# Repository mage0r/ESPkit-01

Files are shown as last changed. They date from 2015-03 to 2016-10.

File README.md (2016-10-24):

ESPkit-01 - The breakout board for learning ESP-01's
=============

This project is designed as an easy to use adapter to connect your ESP-01 device to a standard serial connection.

Version 1.3 has expanded and now includes a full usb-to-serial chip right on the board.  If you'd prefer the simpiler version, follow this link to [Version 1.2](https://github.com/mage0r/ESPkit-01/tree/v1.2).

It has a program/general use button and a ws2812b to play with some blinky leds.  To enable the ws2812b, simply bridge the "pixel on" pads.

Don't forget to jump on to Andy's github and do the workshop! https://github.com/geekscape/nodemcu_esp8266

[Schematic available here](espkit-01.pdf?raw=true "Schematic")

[Gerber](http://gerblook.org/pcb/zZLnKLdKDrQhMTAEMa8F2Y)

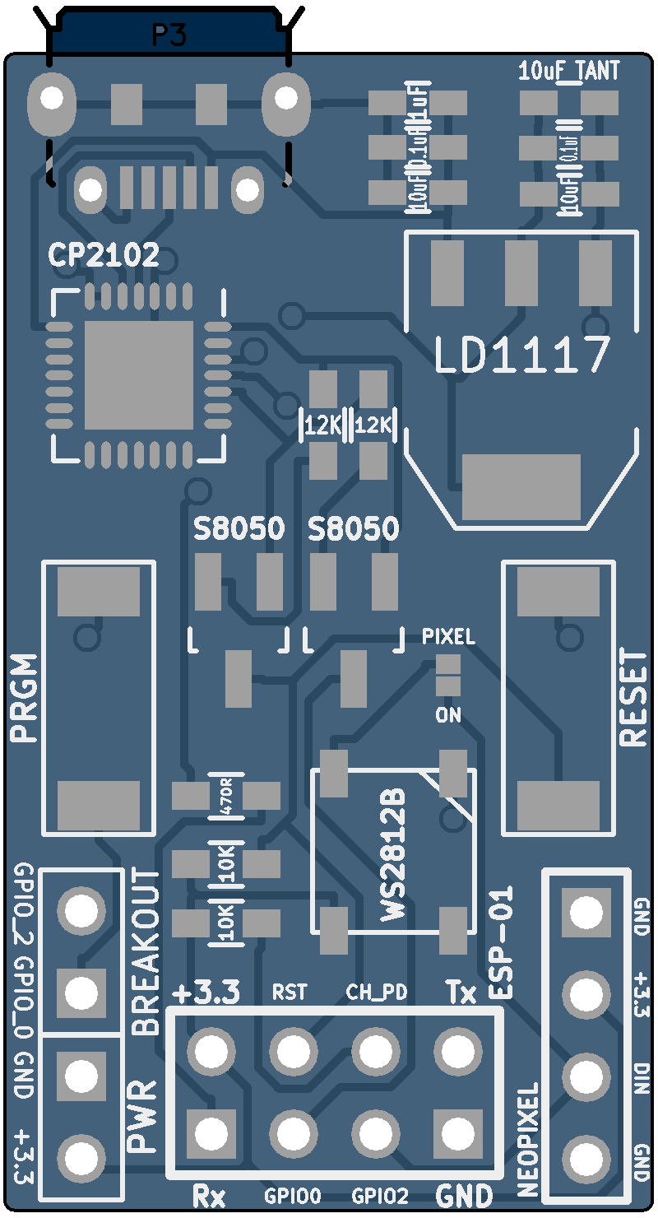
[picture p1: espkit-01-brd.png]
Board Layout board


CREDITS
------------

This project was designed by John Spencer and Andy Gelme
You can see our githubs at:
 - https://github.com/mage0r
 - https://github.com/geekscape

Made at hackmelbourne.org!

SPECIAL THANKS
------------

To the HackMelbourne (CCHS, http://hackmelbourne.org) community of Melbourne, Australia.

To all other open-source developers whose countless hours supported every other aspect of this design.

DISTRIBUTION
------------
The specific terms of distribution of this project are governed by the
license referenced below. Please contact the copyright owner if you wish to modify the board for distribution. Please utilize this design for personal or research projects. Please acknowledge all contributors.

LICENSE
-------
Licensed under the TAPR Open Hardware License (www.tapr.org/OHL).
The "license" sub-folder also contains a copy of this license in plain text format.

Copyright John Spencer, Andy Gelme 2016

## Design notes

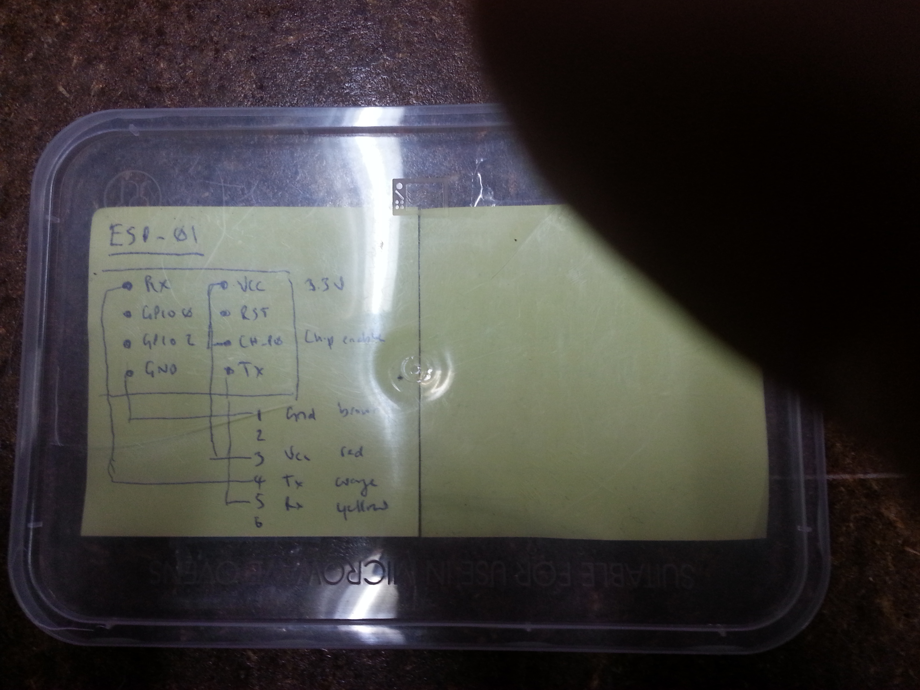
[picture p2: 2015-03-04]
Photos/Early Prototype.jpg

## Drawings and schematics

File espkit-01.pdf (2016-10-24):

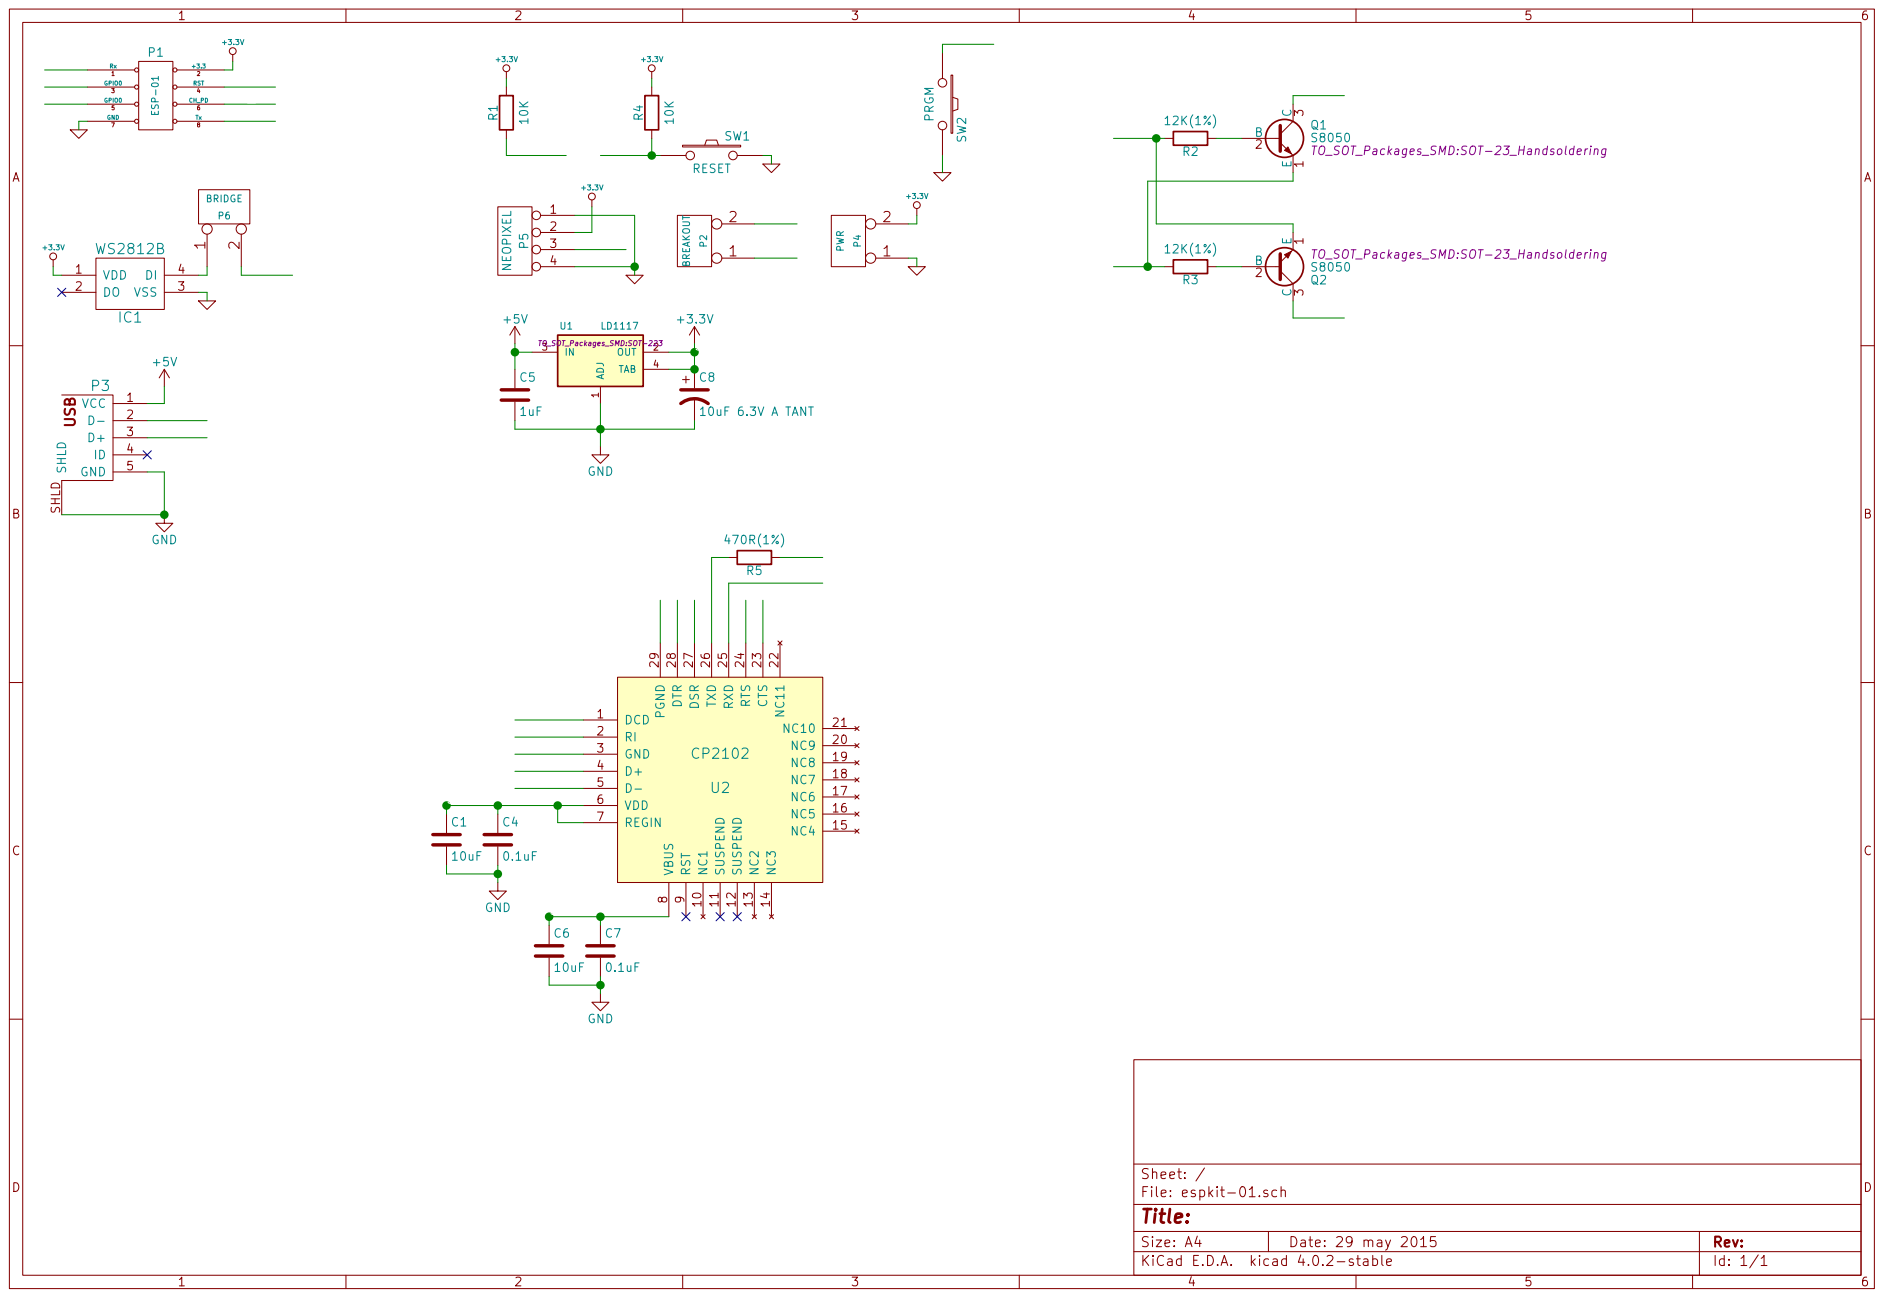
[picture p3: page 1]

File: espkit-01.sch Sheet: / SW2PRGM

9 NC1 10 NC9 20 SUSPEND 11 NC10 21 SUSPEND 12 NC11 22 NC2 13 CTS 23 NC3 14 RTS 24 NC4 15 RXD 25 NC5 16 TXD 26 NC6 17 DSR 27 NC7 18 DTR 28 NC8 19 PGND 29 U2 CP2102 USBVCC 1 D- 2 D+ 3

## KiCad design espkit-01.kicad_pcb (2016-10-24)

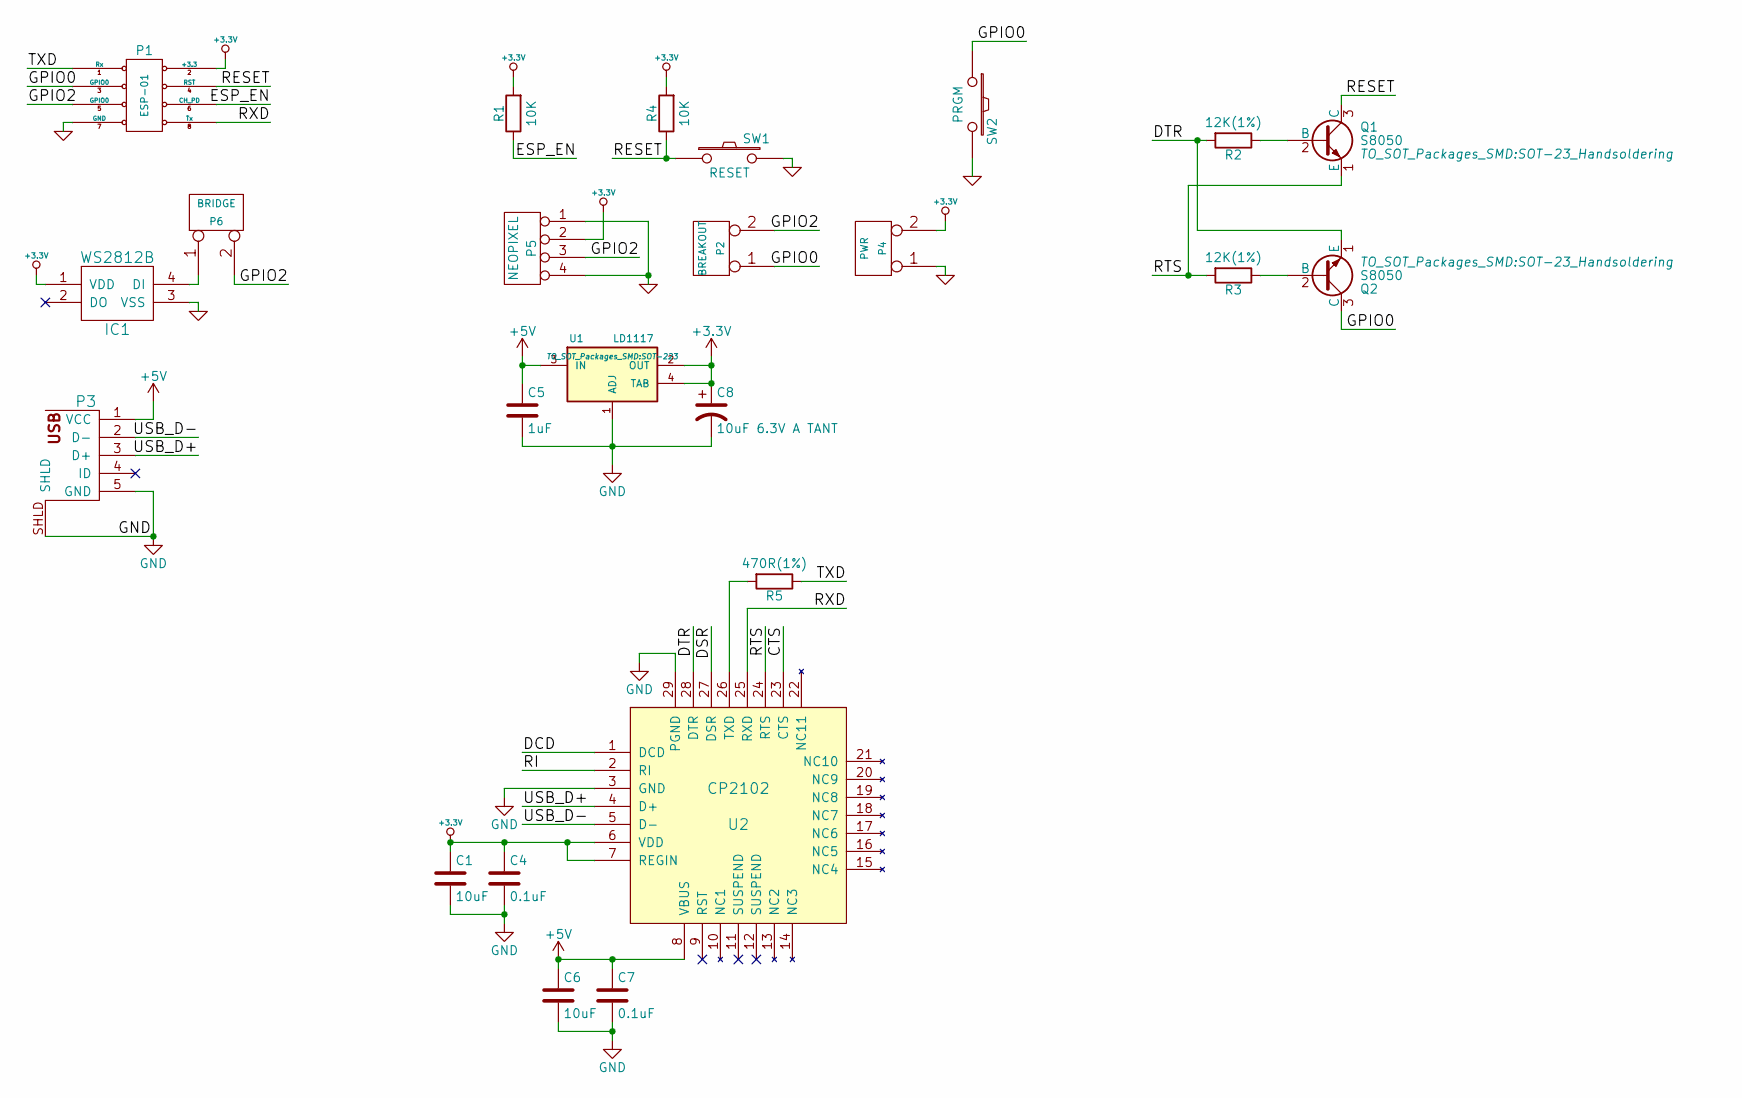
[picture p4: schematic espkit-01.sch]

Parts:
C1, C6: 10uF; C_0603_HandSoldering
C4, C7: 0.1uF; C_0603_HandSoldering
C5: 1uF; C_0603_HandSoldering
C8: 10uF 6.3V A TANT; C_0603_HandSoldering
IC1: WS2812B; ws2812b
P1: ESP-01; Pin_Header_Straight_2x04
P2: BREAKOUT; Pin_Header_Straight_1x02
P3: USB_5PIN_SHELL; USB-MICRO-5pin_PTHMOUNT
P4: PWR; Pin_Header_Straight_1x02
P5: NEOPIXEL; Pin_Header_Straight_1x04
P6: BRIDGE; 603_bridge
Q1, Q2: S8050; SOT-23_Handsoldering
R1, R4: 10K; R_0603_HandSoldering
R2, R3: 12K(1%); R_0603_HandSoldering
R5: 470R(1%); R_0603_HandSoldering
SW1: RESET; 1107G
SW2: PRGM; 1107G
U1: LD1117; SOT-223
U2: CP2102; QFN-28-1EP_5x5mm_Pitch0.5mm

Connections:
+5V: C5.1, C6.1, C7.1, P3.1 (VCC), U1.3 (IN), U2.8 (VBUS)
/CTS: U2.23 (CTS)
/DCD: U2.1 (DCD)
/DSR: U2.27 (DSR)
/DTR: Q2.1 (E), R2.2, U2.28 (DTR)
/ESP_EN: P1.6 (CH_PD), R1.1
/GPIO0: P1.3 (GPIO0), P2.1, Q2.3 (C), SW2.1
/GPIO2: P1.5 (GPIO0), P2.2 (PM), P5.3, P6.2 (PM)
/RESET: P1.4 (RST), Q1.3 (C), R4.1, SW1.1
/RI: U2.2 (RI)
/RTS: Q1.1 (E), R3.2, U2.24 (RTS)
/RXD: P1.8 (Tx), U2.25 (RXD)
/TXD: P1.1 (Rx), R5.1
/USB_D+: P3.3 (D+), U2.4 (D+)
/USB_D-: P3.2 (D-), U2.5 (D-)
GND: C1.2, C4.2, C5.2, C6.2, C7.2, C8.2, IC1.3 (VSS), P1.7 (GND), P3.5 (GND), P3.SHLD, P4.1, P5.1, P5.4, SW1.2, SW2.2, U1.1 (ADJ), U2.3 (GND), U2.29 (PGND)
unnamed: IC1.4 (DI), P6.1
unnamed: Q1.2 (B), R2.1
unnamed: Q2.2 (B), R3.1
unnamed: R5.2, U2.26 (TXD)

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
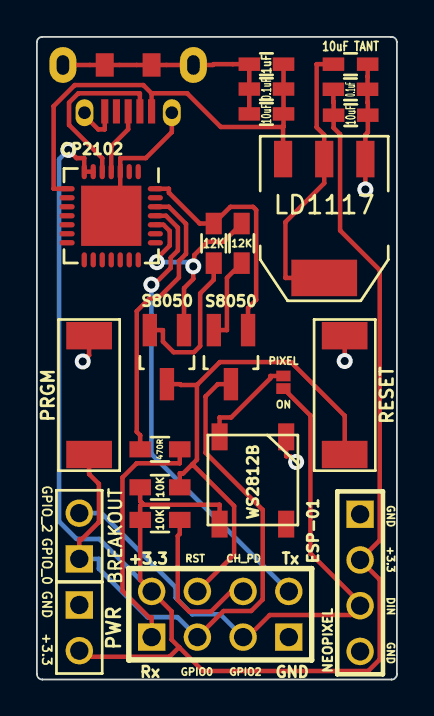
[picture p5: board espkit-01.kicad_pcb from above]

Board: 2 copper layers, 20.0 x 35.7 mm, 24 parts (0 on the bottom side), 18 nets.

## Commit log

2015-02-28 Updated text.
    [espkit-01.kicad_pcb]
2015-03-04 Added Early prototype Photo
2015-03-07 Added single layer version
    or, at least, as single as possible. There are 4 connections on the
    back, but they are between pins.
    [espkit-01.dsn, espkit-01.kicad_pcb, espkit-01.sch]
2015-03-12 Turns out my kinsten gerbers are a bit thin
2015-03-13 Shuffled Layout for 1.1
    [espkit-01.dsn, espkit-01.kicad_pcb, espkit-01.sch]
2015-03-14 Updated board and layout.
    [espkit-01.kicad_pcb]
2015-05-29 Redundant power led removed
    bridge connection now easy to get too.
    [espkit-01.dsn, espkit-01.kicad_pcb, espkit-01.sch]
2016-10-24 New Design with auto program.
    You should be able to do away with the serial/usb programmer and just use the NodeMCU v1.0 board in Arduino to auto-program.
    [espkit-01.dsn, espkit-01.kicad_pcb, espkit-01.sch]
2016-10-24 Updated readme and documentation.
    [espkit-01.kicad_pcb]
2016-10-24 Sometimes helps to connect your grounds.
    [espkit-01.dsn, espkit-01.kicad_pcb, espkit-01.sch]
